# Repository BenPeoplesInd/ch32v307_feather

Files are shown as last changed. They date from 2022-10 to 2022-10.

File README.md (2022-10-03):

# ch32v307_feather
Feather-ish board for ch32v307rct6

This is a rough pass at a ch32v307 feather using the 64-pin variant of the CH32V307.   

At this moment it's untested (I'm ordering them now).    USB-C for the programming adapter.

A few notes vs. the official feather:

- I've omitted the LiPo stack
- Current vreg is only 100mA
- BOOT button connects BOOT0 to 3.3V to enable bootloader over USB
- There's no debug via USB (unless you write one)
- No SWD breakout
- Includes 5.1k resistors for USB-C PD
- All the GPIOs are ADC capable
- Did not breakout the ethernet pins anywhere, which might actually be super useful.  
- No status/indicator LEDs
- SPI is SPI2
- i2c is also USB2
- Schematic is messy and poorly documented

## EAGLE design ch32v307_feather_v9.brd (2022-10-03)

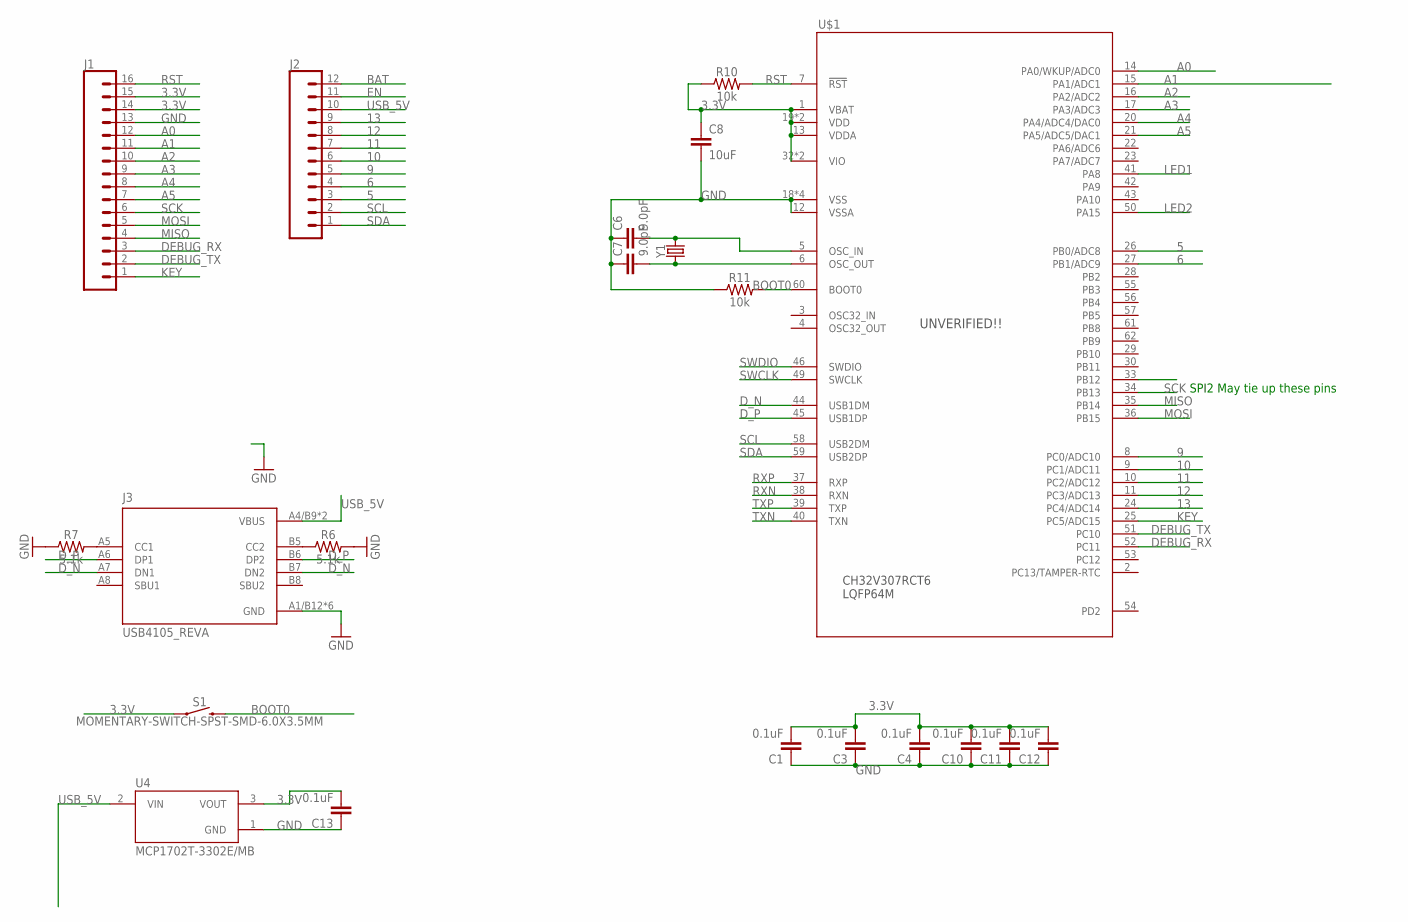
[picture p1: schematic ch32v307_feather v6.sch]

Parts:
C1, C3, C4, C10, C11, C12, C13: 0.1uF; 0603-CAP
C6, C7: 9.0pF; 0603
C8: 10uF; 1210
J1: CONN_16; 1X16
J2: CONN_12; 1X12
J3: USB4105_REVA; GCT_USB4105_REVA
R6, R7: 5.1k; 0603
R10, R11: 10k; 0603
S1: MOMENTARY-SWITCH-SPST-SMD-6.0X3.5MM; TACTILE_SWITCH_SMD_6.0X3.5MM
U4: MCP1702T-3302E/MB; REG_MCP1702T-3302E/MB
U$1: CH32V307RCT6; LQFP64M
Y1: CRYSTALSMD-3.2X2.5; CRYSTAL-SMD-3.2X2.5MM

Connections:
3.3V: C1.2, C3.2, C4.2, C8.1, C10.2, C11.2, C12.2, C13.2, J1.14, J1.15, R10.1, S1.1, U4.3 (VOUT), U$1.1 (VBAT), U$1.13 (VDDA), U$1.19 (VDD), U$1.32 (VIO), U$1.48 (VDD), U$1.64 (VIO)
5: J2.3, U$1.26 (PB0/ADC8)
6: J2.4, U$1.27 (PB1/ADC9)
9: J2.5, U$1.8 (PC0/ADC10)
10: J2.6, U$1.9 (PC1/ADC11)
11: J2.7, U$1.10 (PC2/ADC12)
12: J2.8, U$1.11 (PC3/ADC13)
13: J2.9, U$1.24 (PC4/ADC14)
A0: J1.12, U$1.14 (PA0/WKUP/ADC0)
A1: J1.11, U$1.15 (PA1/ADC1)
A2: J1.10, U$1.16 (PA2/ADC2)
A3: J1.9, U$1.17 (PA3/ADC3)
A4: J1.8, U$1.20 (PA4/ADC4/DAC0)
A5: J1.7, U$1.21 (PA5/ADC5/DAC1)
BAT: J2.12
BOOT0: R11.2, S1.2, U$1.60 (BOOT0)
DEBUG_RX: J1.3, U$1.52 (PC11)
DEBUG_TX: J1.2, U$1.51 (PC10)
D_N: J3.A7 (DN1), J3.B7 (DN2), U$1.44 (USB1DM)
D_P: J3.A6 (DP1), J3.B6 (DP2), U$1.45 (USB1DP)
EN: J2.11
GND: C1.1, C3.1, C4.1, C6.1, C7.1, C8.2, C10.1, C11.1, C12.1, C13.1, J1.13, J3.A1/B12 (GND), J3.B1/A12 (GND), J3.G1 (GND), J3.G2 (GND), J3.G3 (GND), J3.G4 (GND), R6.2, R7.1, R11.1, U4.1 (GND), U$1.12 (VSSA), U$1.18 (VSS), U$1.31 (VSS), U$1.47 (VSS), U$1.63 (VSS)
KEY: J1.1, U$1.25 (PC5/ADC15)
LED1: U$1.41 (PA8)
LED2: U$1.50 (PA15)
MISO: J1.4, U$1.35 (PB14)
MOSI: J1.5, U$1.36 (PB15)
unnamed: C6.2, U$1.5 (OSC_IN), Y1.3 (2)
unnamed: C7.2, U$1.6 (OSC_OUT), Y1.1
unnamed: J3.B5 (CC2), R6.1
unnamed: J3.A5 (CC1), R7.2
RST: J1.16, R10.2, U$1.7 (!RST)
RXN: U$1.38 (RXN)
RXP: U$1.37 (RXP)
SCK: J1.6, U$1.34 (PB13)
SCL: J2.2, U$1.58 (USB2DM)
SDA: J2.1, U$1.59 (USB2DP)
SWCLK: U$1.49 (SWCLK)
SWDIO: U$1.46 (SWDIO)
TXN: U$1.40 (TXN)
TXP: U$1.39 (TXP)
USB_5V: J2.10, J3.A4/B9 (VBUS), J3.B4/A9 (VBUS), U4.2 (VIN)

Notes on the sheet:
SPI2 May tie up these pins

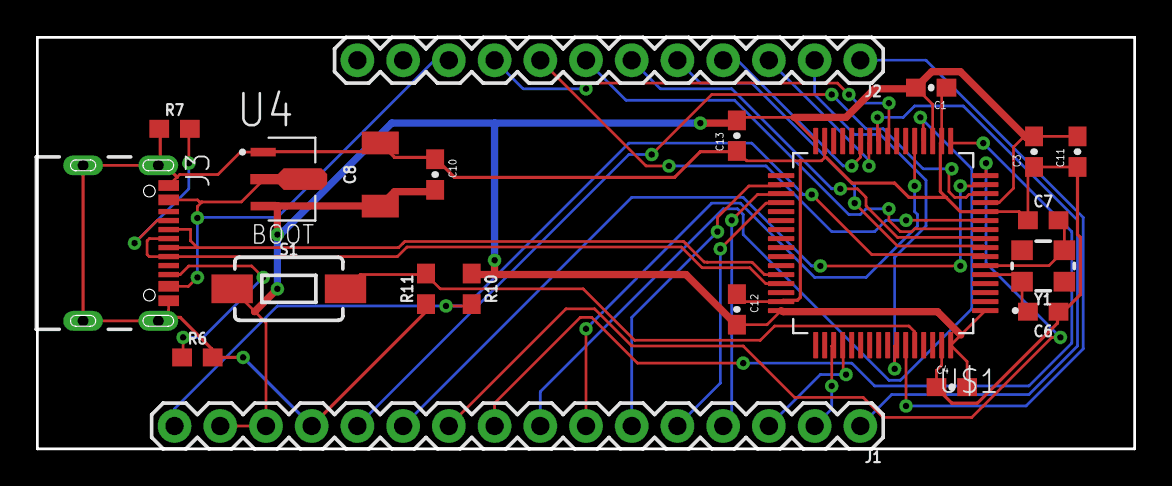
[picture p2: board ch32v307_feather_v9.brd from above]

Board: 2 copper layers, 61.0 x 22.9 mm, 21 parts (0 on the bottom side), 32 nets.

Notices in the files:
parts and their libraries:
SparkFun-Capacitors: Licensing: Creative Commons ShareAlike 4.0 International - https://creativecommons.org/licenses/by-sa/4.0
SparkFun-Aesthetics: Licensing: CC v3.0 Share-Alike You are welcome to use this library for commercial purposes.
